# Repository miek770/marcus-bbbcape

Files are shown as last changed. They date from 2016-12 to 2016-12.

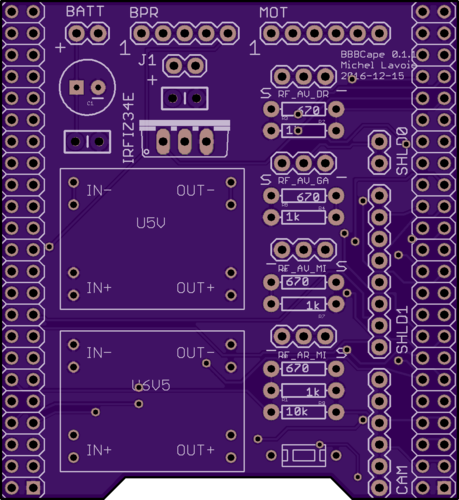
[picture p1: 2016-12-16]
media/Board top.png

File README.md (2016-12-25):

# marcus-bbbcape

Beaglebone Black cape for my robot, see:

- [marcus-base](https://github.com/miek770/marcus-base)
- [marcus-boucliers](https://github.com/miek770/marcus-boucliers)

The general goal is to reduce the amount of loose wires on the robot and the required space. The current platform is not compact at all, and adding more stuff (ex.: cannon, turrent, shields) seems like quite the challenge.

Ideally I would use Molex connectors but it would probably eat up too much space. I would like to keep the PCB as small as possible, mostly to keep the cost down. Right-angle headers would work as well, but I think I'll quickly run out of borders. Perhaps right-angle headers for stuff going down, and straight headers for stuff going up?

The cape should be stackable, which means that P8 and P9 should be female headers with long leads. The alternative would be male headers mounted on the bottom. Then again, with plenty of headers going up I probably won't be able to put another cape on top anyways. Still, having female headers allows me to add wires in the future for unplanned expansions.

## 1. To do list

- Add UART2;
- Add battery voltage monitoring (remember the 1.8V analog input limitation);
- Move the top headers' titles below them, otherwise they will be hidden by the right-angle headers I plan on using;
- Correct title, it's partially hidden by the P9 header;
- Output 6.5V somewhere other than for the camera. Some other system may very well need it;
- I don't like how the rangefinders' pins are mirrored, but I've added indications. If it's not too complicated I'd like to mirror 2 of them;
- Add an LED tied to an unused pin, for testing purposes;
- Double-check the big capacitor polarity. I would've thought the square pad to be for the negative pin, but the top silk screen says otherwise;
- Add headers 1st pin markers on all of them and resize the existing 1's (not existing ones but existing 1's);
- Document pins usage. Just need to integrate this info in marcus-base/modules/pins.py which holds a dictionary of pins usage.

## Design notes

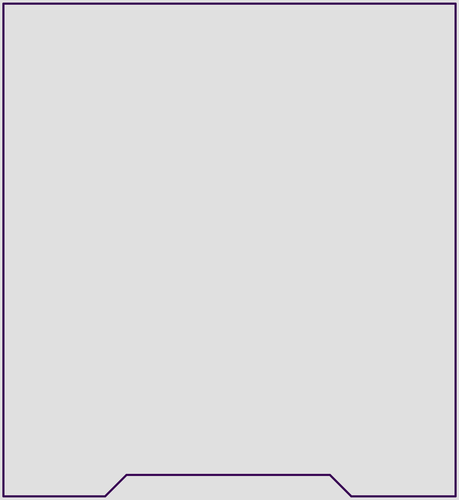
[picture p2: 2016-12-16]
media/Board outline.png

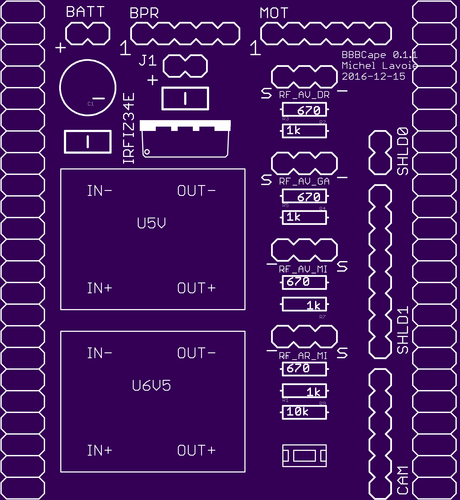
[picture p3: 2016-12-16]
media/Top silk screen.png

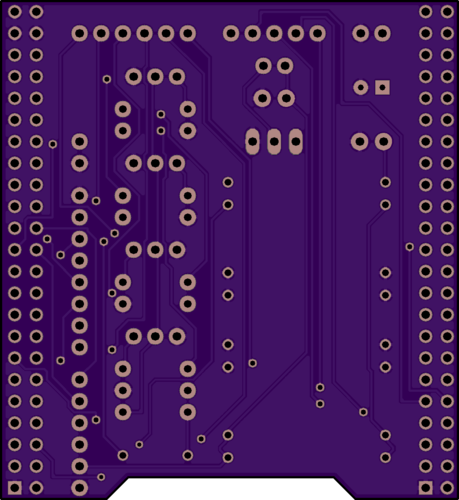
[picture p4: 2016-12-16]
media/Board bottom.png

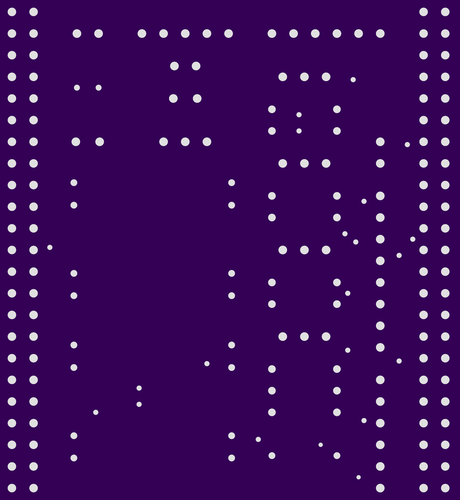
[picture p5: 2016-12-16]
media/Drills.png

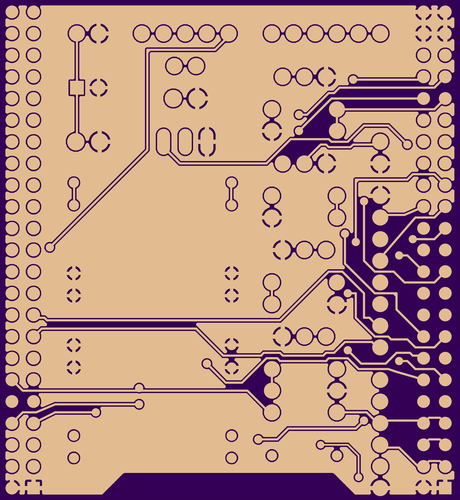
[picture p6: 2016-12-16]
media/Top layer.png

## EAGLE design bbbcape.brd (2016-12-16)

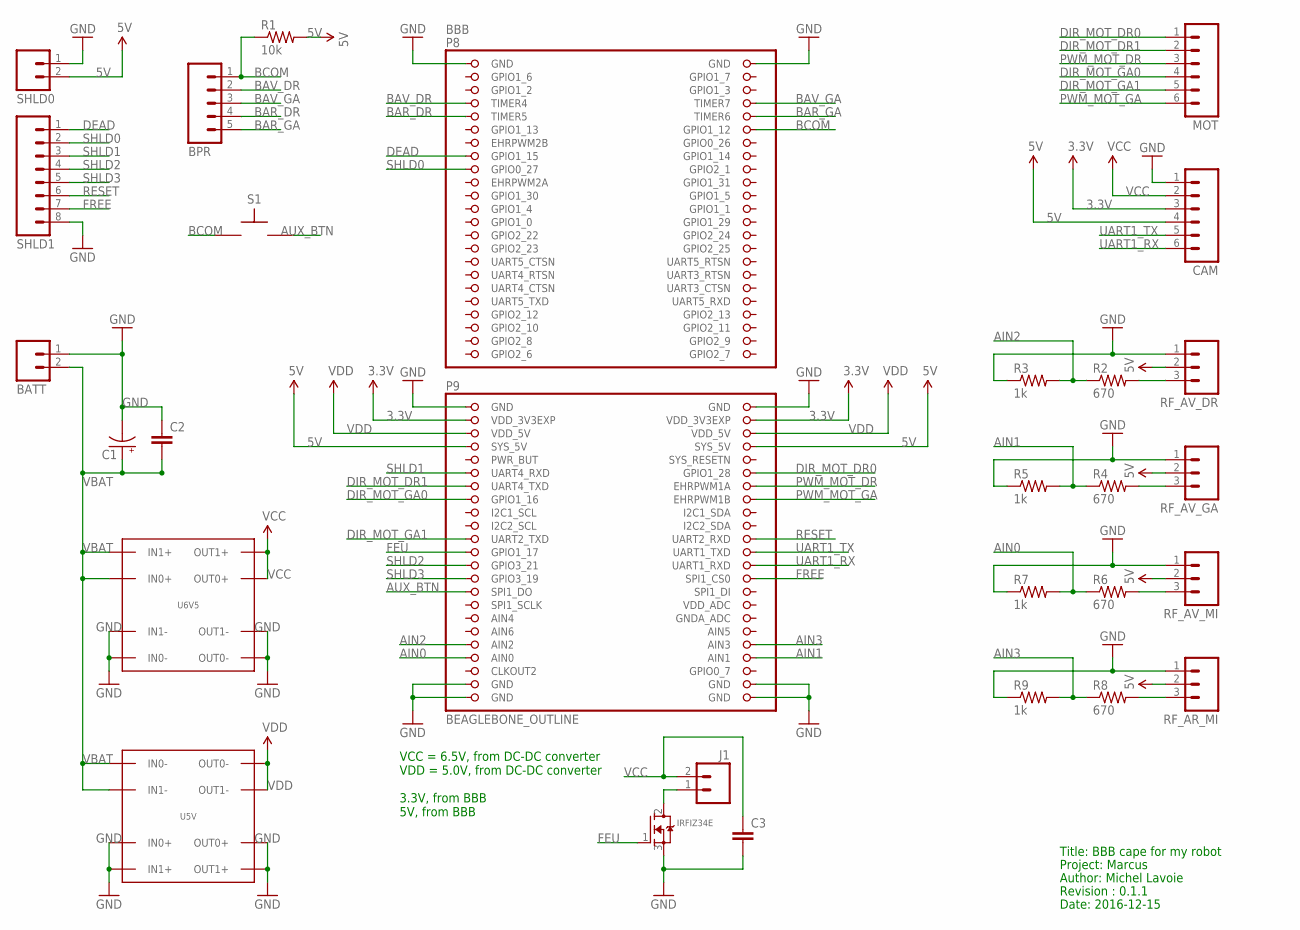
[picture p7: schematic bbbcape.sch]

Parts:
BATT: M02PTH; 1X02
BBB: BEAGLEBONE_OUTLINE; BEAGLEBONE_SHIELD
BPR: M05PTH; 1X05
C1: 100UF-25V-20%(PTH); CPOL-RADIAL-100UF-25V
C2, C3: 0.1UF-50V-20%(PTH)KIT-EZ; CAP-PTH-SMALL-KIT
CAM: M06SILK_FEMALE_PTH; 1X06
IRFIZ34E: MOSFET-NGDS_TO220V; TO220V
J1: M02PTH; 1X02
MOT: M06SILK_FEMALE_PTH; 1X06
R1: 10k; AXIAL-0.3
R2, R4, R6, R8: 670; AXIAL-0.3
R3, R5, R7, R9: 1k; AXIAL-0.3
RF_AR_MI: M03PTH; 1X03
RF_AV_DR: M03PTH; 1X03
RF_AV_GA: M03PTH; 1X03
RF_AV_MI: M03PTH; 1X03
S1: TACTILE-SPST-6MM-SLIM; 6MM-SLIM
SHLD0: M02PTH; 1X02
SHLD1: M08; 1X08_ROUND
U5V, U6V5: SEEED-MP1584

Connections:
3.3V: BBB.49 (VDD_3V3EXP), BBB.50 (VDD_3V3EXP), CAM.3
5V: BBB.53 (SYS_5V), BBB.54 (SYS_5V), CAM.4, R1.P$2 (2), RF_AR_MI.2, RF_AV_DR.2, RF_AV_GA.2, RF_AV_MI.2, SHLD0.2
AIN0: BBB.85 (AIN0), R6.P$1 (1), R7.P$2 (2)
AIN1: BBB.86 (AIN1), R4.P$1 (1), R5.P$2 (2)
AIN2: BBB.83 (AIN2), R2.P$1 (1), R3.P$2 (2)
AIN3: BBB.84 (AIN3), R8.P$1 (1), R9.P$2 (2)
AUX_BTN: BBB.75 (SPI1_DO), S1.P$2
BAR_DR: BBB.9 (TIMER5), BPR.4
BAR_GA: BBB.10 (TIMER6), BPR.5
BAV_DR: BBB.7 (TIMER4), BPR.2
BAV_GA: BBB.8 (TIMER7), BPR.3
BCOM: BBB.12 (GPIO1_12), BPR.1, R1.P$1 (1), S1.P$1
DEAD: BBB.15 (GPIO1_15), SHLD1.1
DIR_MOT_DR0: BBB.58 (GPIO1_28), MOT.1
DIR_MOT_DR1: BBB.59 (UART4_TXD), MOT.2
DIR_MOT_GA0: BBB.61 (GPIO1_16), MOT.4
DIR_MOT_GA1: BBB.67 (UART2_TXD), MOT.5
FEU: BBB.69 (GPIO1_17), IRFIZ34E.1 (G)
FREE: BBB.74 (SPI1_CS0), SHLD1.7
GND: BATT.1, BBB.1 (GND), BBB.2 (GND), BBB.47 (GND), BBB.48 (GND), BBB.89 (GND), BBB.90 (GND), BBB.91 (GND), BBB.92 (GND), C1.2 (-), C2.1, C3.2, CAM.1, IRFIZ34E.3 (S), R3.P$1 (1), R5.P$1 (1), R7.P$1 (1), R9.P$1 (1), RF_AR_MI.1, RF_AV_DR.1, RF_AV_GA.1, RF_AV_MI.1, SHLD0.1, SHLD1.8, U5V.IN0+, U5V.IN1+, U5V.OUT0+, U5V.OUT1+, U6V5.IN0-, U6V5.IN1-, U6V5.OUT0-, U6V5.OUT1-
unnamed: R2.P$2 (2), RF_AV_DR.3
unnamed: R4.P$2 (2), RF_AV_GA.3
unnamed: IRFIZ34E.2 (D), J1.1
unnamed: R6.P$2 (2), RF_AV_MI.3
unnamed: R8.P$2 (2), RF_AR_MI.3
PWM_MOT_DR: BBB.60 (EHRPWM1A), MOT.3
PWM_MOT_GA: BBB.62 (EHRPWM1B), MOT.6
RESET: BBB.68 (UART2_RXD), SHLD1.6
SHLD0: BBB.17 (GPIO0_27), SHLD1.2
SHLD1: BBB.57 (UART4_RXD), SHLD1.3
SHLD2: BBB.71 (GPIO3_21), SHLD1.4
SHLD3: BBB.73 (GPIO3_19), SHLD1.5
UART1_RX: BBB.72 (UART1_RXD), CAM.6
UART1_TX: BBB.70 (UART1_TXD), CAM.5
VBAT: BATT.2, C1.1 (+), C2.2, U5V.IN0-, U5V.IN1-, U6V5.IN0+, U6V5.IN1+
VCC: C3.1, CAM.2, J1.2, U6V5.OUT0+, U6V5.OUT1+
VDD: BBB.51 (VDD_5V), BBB.52 (VDD_5V), U5V.OUT0-, U5V.OUT1-

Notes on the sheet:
Title: BBB cape for my robot
Project: Marcus
Author: Michel Lavoie
Revision : 0.1.1
Date: 2016-12-15
VCC = 6.5V, from DC-DC converter VDD = 5.0V, from DC-DC converter 3.3V, from BBB 5V, from BBB

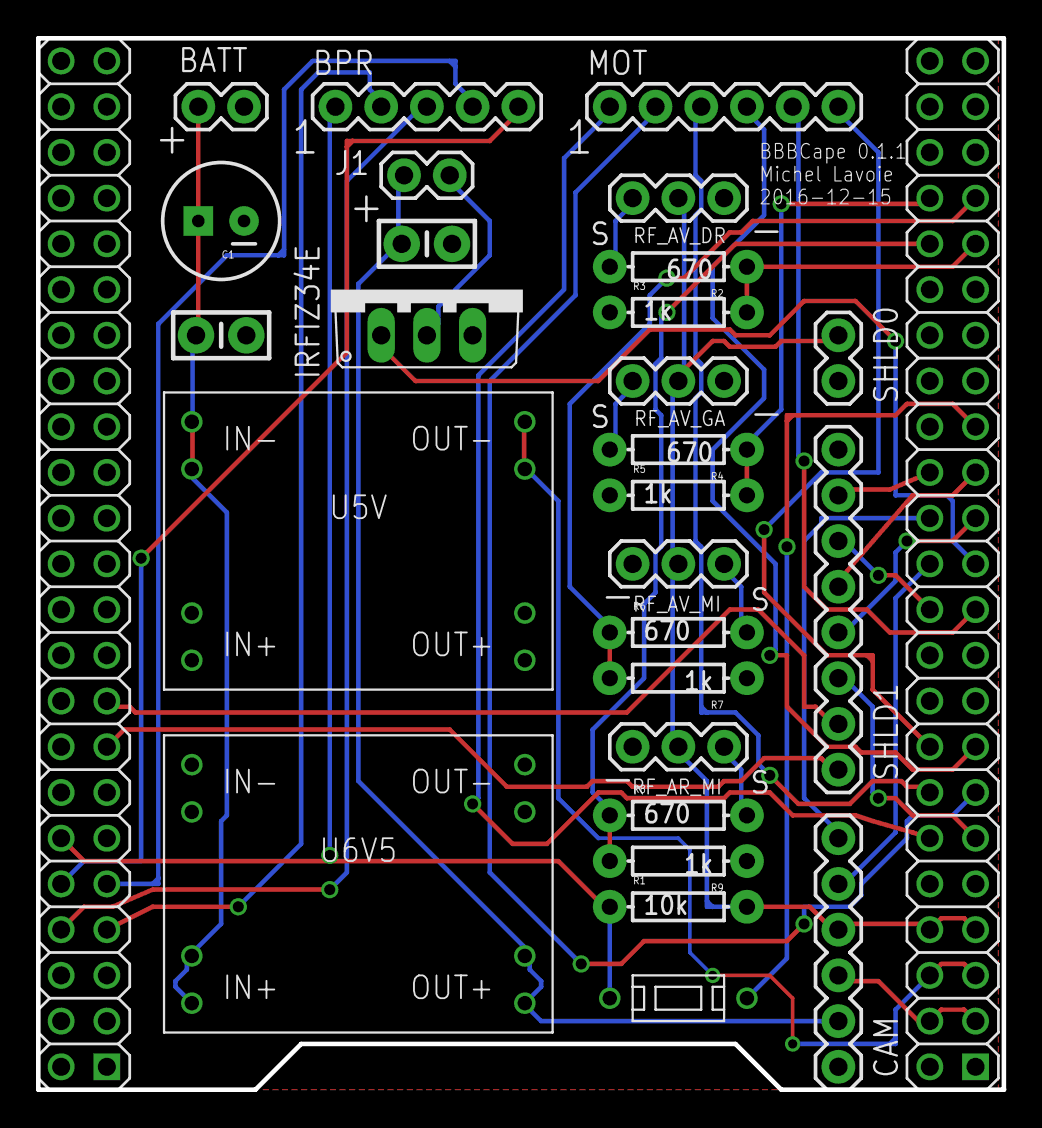
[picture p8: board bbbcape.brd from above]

Board: 2 copper layers, 53.7 x 58.4 mm, 28 parts (0 on the bottom side), 37 nets.

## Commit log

2016-12-11 Started schematic and to do list.
    [bbbcape.brd, bbbcape.sch]
2016-12-11 Connected motors.
    [bbbcape.brd, bbbcape.sch]
2016-12-11 Connected CMUCam2+.
    [bbbcape.brd, bbbcape.sch]
2016-12-11 Connected bumpers.
    [bbbcape.brd, bbbcape.sch]
2016-12-11 Added frame.
    [bbbcape.sch]
2016-12-11 Connected GP2D12 rangefinders.
    [bbbcape.brd, bbbcape.sch]
2016-12-11 Connected shields.
    [bbbcape.brd, bbbcape.sch]
2016-12-11 Added and connected firing circuit.
    [bbbcape.brd, bbbcape.sch]
2016-12-11 Added reset button (on BAR_GA, P8_10).
    [bbbcape.brd, bbbcape.sch]
2016-12-11 Replaced S1
    [bbbcape.sch]
2016-12-13 Added schematic image.
2016-12-16 Added new DC-DC converter symbol (instead of headers).
    [bbbcape.brd, bbbcape.sch]
2016-12-16 Switched a few pins to confirmed useable pins.
    [bbbcape.brd, bbbcape.sch]
2016-12-16 PCB done.
    [bbbcape.brd, bbbcape.sch]
2016-12-16 Trying to reduce the board overall dimensions, no success...
    [bbbcape.brd]
2016-12-16 Board outline is now fine.
    [bbbcape.brd, bbbcape.sch]
2016-12-16 Added notes for version 0.1.2, before ordering the PCB.

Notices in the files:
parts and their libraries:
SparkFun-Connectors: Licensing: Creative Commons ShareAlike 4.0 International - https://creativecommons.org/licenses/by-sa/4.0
